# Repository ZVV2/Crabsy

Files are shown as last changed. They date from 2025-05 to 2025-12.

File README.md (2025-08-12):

<p align="center">
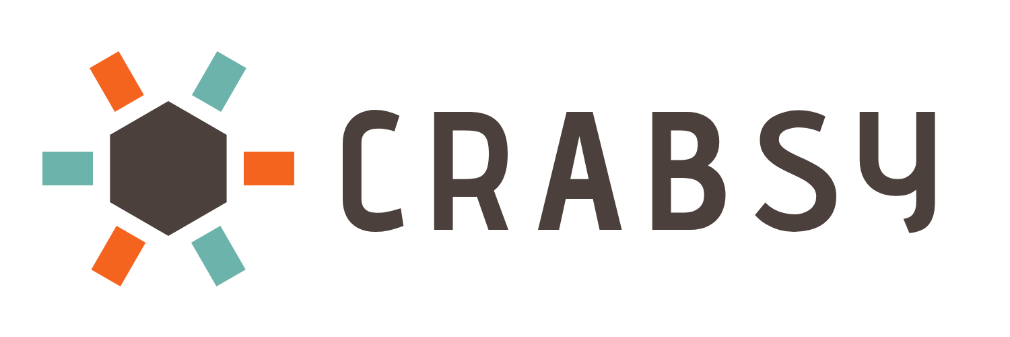
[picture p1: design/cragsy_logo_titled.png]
    
</p>

---

A robotic crab, designed as a hexapod to be taught and controlled by AI.

This repo contains purely the hardware (construction, electronics and related calculations). The operating system [CrabOS](https://github.com/ZVV2/CrabOS), the APIs [CrabAPIs](https://github.com/ZVV2/CrabAPI) and the AI/simulation [CrabRave](https://github.com/ZVV2/CrabRave) each have their own repos.

<p align="center">
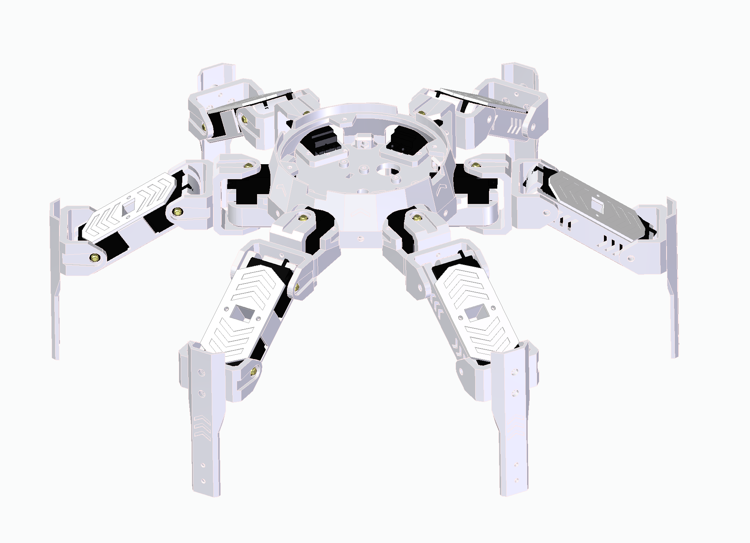
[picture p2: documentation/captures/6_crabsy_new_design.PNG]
    
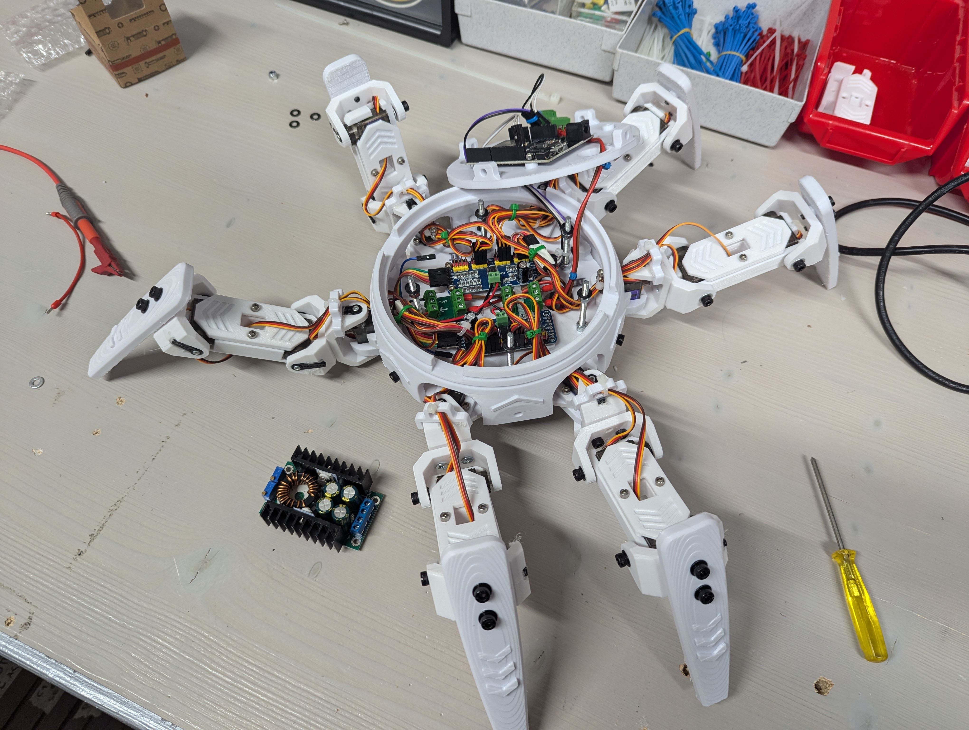
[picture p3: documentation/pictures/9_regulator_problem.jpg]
    
</p>

A full documentation is available [here](documentation/README.md). For further reading on the projects history and creation, read the [project log](documentation/project_log.md). To get an overview over recent changes see the [changelog](CHANGELOG.md).

The robot is designed and created by a [small team](https://github.com/ZVV2) as a fun little side project. We have no economic goals with it, feel free to use whatever you deem useful and let us know!

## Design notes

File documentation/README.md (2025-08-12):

<p align="center">
    
</p>

--- 

Full documentation for the Crabsy robot for the version 0.1.0/2025/05/27. For details on design/build choices and project history see the [project log](./project_log.md).

<h2>Overview</h2>

- [Construction](#construction)
- [Electronics](#electronics)

## Construction

## Electronics

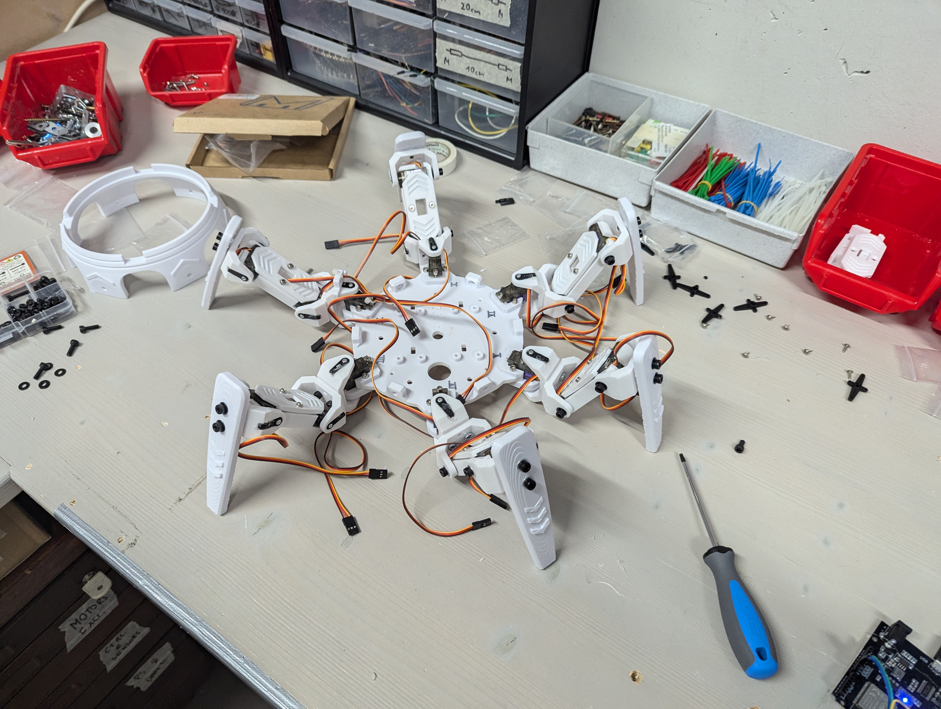
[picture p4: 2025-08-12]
documentation/pictures/2_hexapod_done_1.jpg

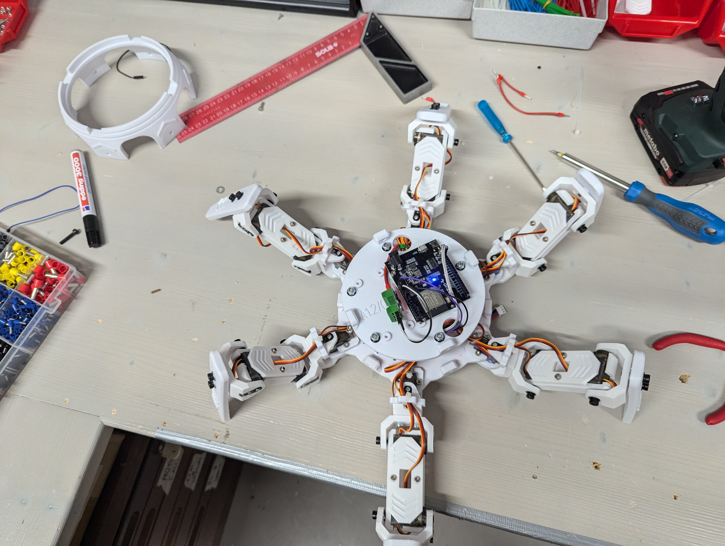
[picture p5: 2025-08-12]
documentation/pictures/7_next_layer_3.jpg

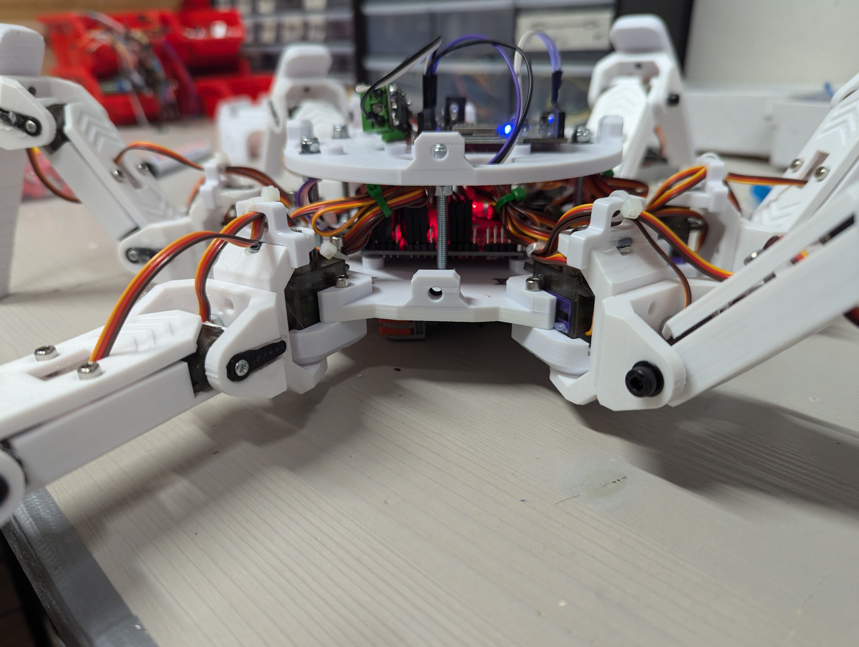
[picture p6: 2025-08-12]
documentation/pictures/6_next_layer_2.jpg

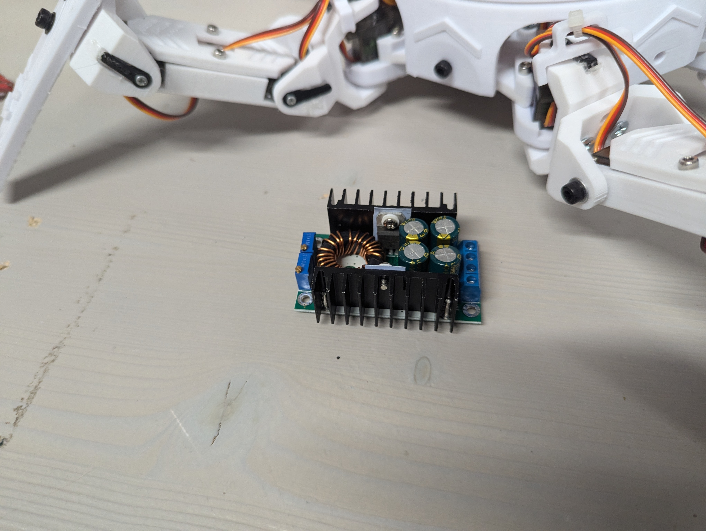
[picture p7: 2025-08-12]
documentation/pictures/10_regulator.jpg

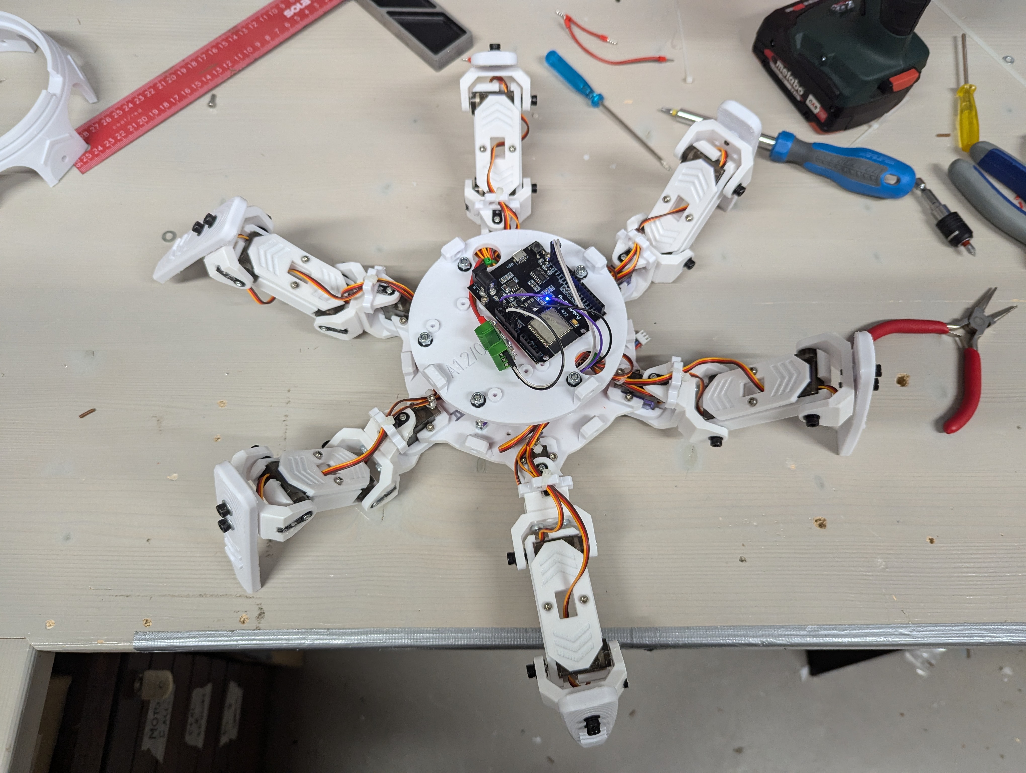
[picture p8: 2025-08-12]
documentation/pictures/8_next_layer_4.jpg

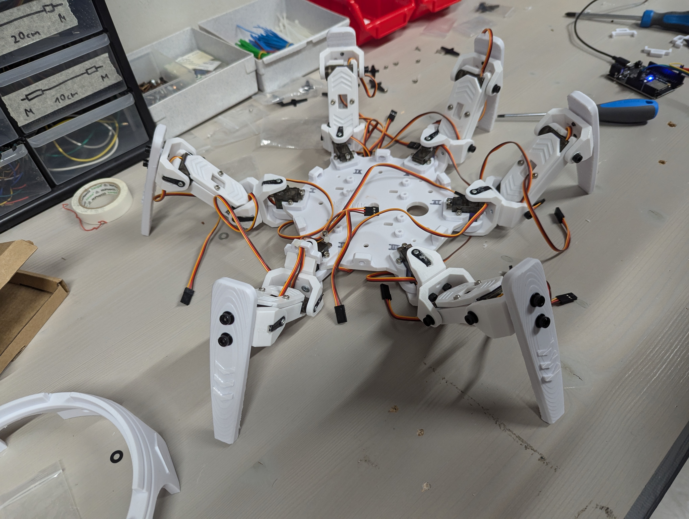
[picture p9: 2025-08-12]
documentation/pictures/4_hexapod_done_3.jpg

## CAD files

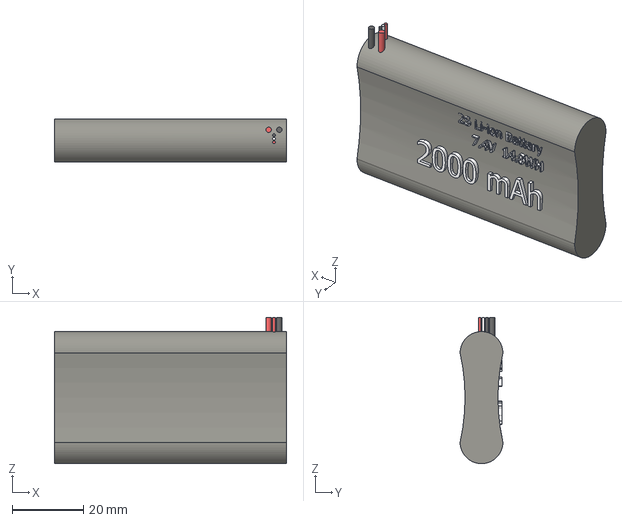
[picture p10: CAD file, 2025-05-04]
construction/a1_base/e_electronics/e2_battery_7.4V_2000mah/raw/Battery_Li-ion.stp
65.0 x 12.0 x 41.0 mm

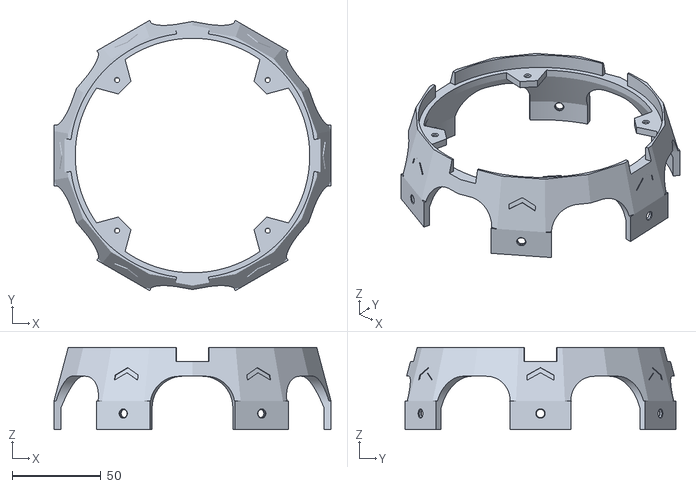
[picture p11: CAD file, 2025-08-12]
construction/a1_base/stl/3_lower_carapace.stl
156.0 x 152.4 x 46.2

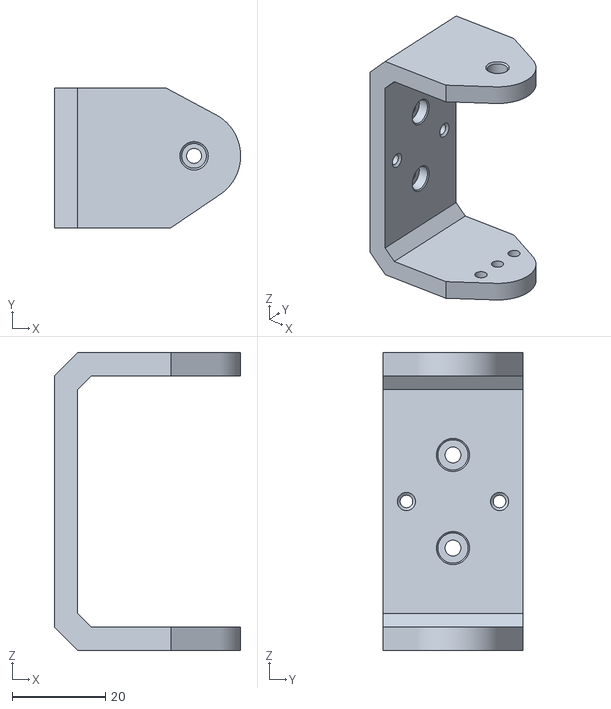
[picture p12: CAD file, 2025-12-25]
construction/a2_leg/stl/5_connector.stl
40.0 x 30.0 x 64.0

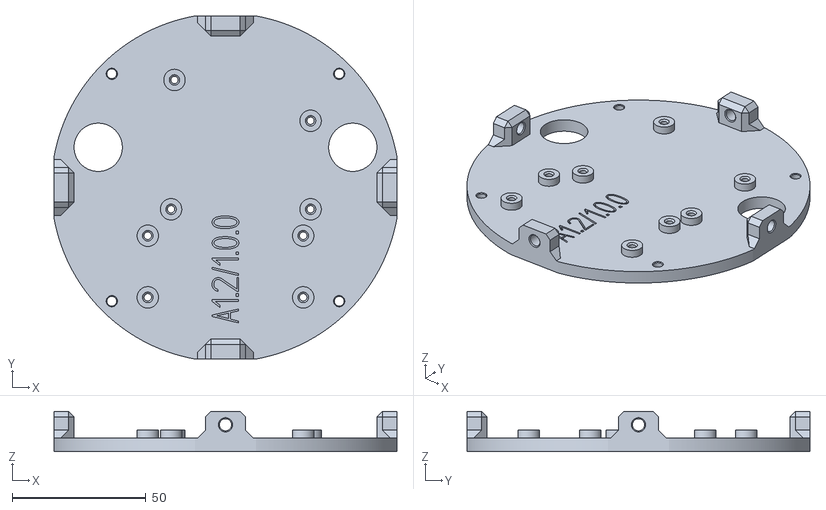
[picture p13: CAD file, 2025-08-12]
construction/a1_base/stl/2_top_plate.stl
128.0 x 128.0 x 15.0

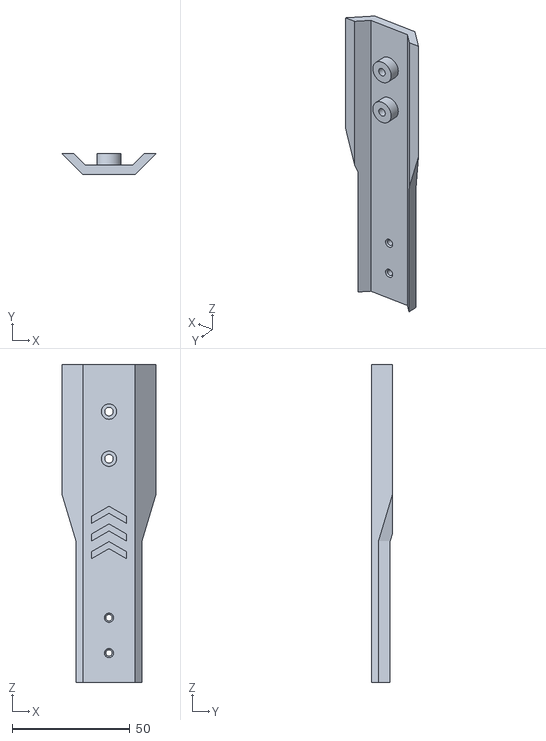
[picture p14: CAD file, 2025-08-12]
construction/a2_leg/stl/4_foot_shell.stl
40.0 x 9.00 x 135.0

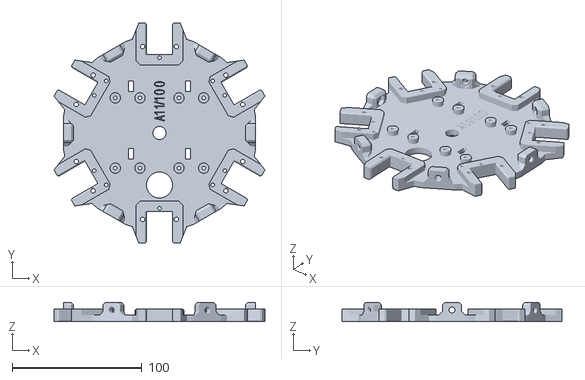
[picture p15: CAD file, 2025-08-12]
construction/a1_base/stl/1_base_plate.stl
162.4 x 169.0 x 15.0

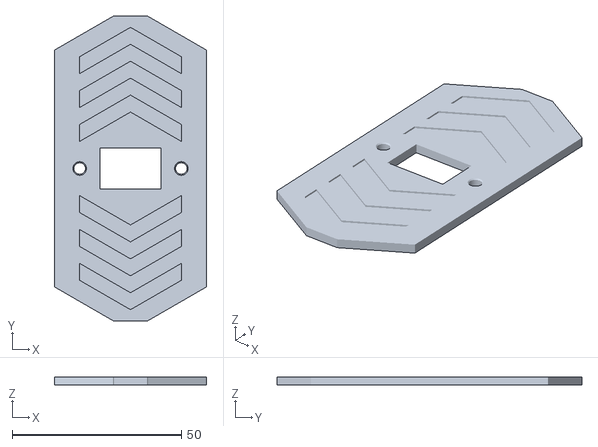
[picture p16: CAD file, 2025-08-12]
construction/a2_leg/stl/3_middle_cap.stl
45.0 x 90.0 x 2.50

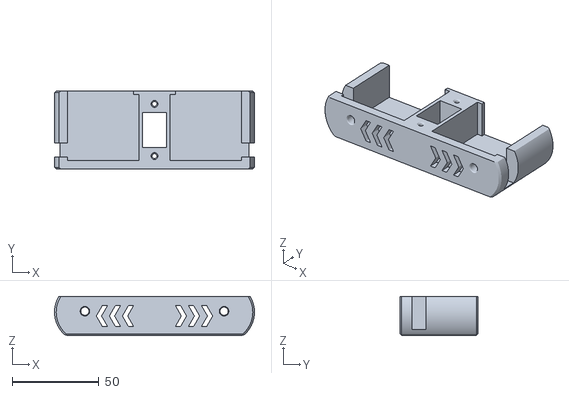
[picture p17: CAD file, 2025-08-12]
construction/a2_leg/stl/2_middle_segment.stl
115.0 x 45.0 x 22.5

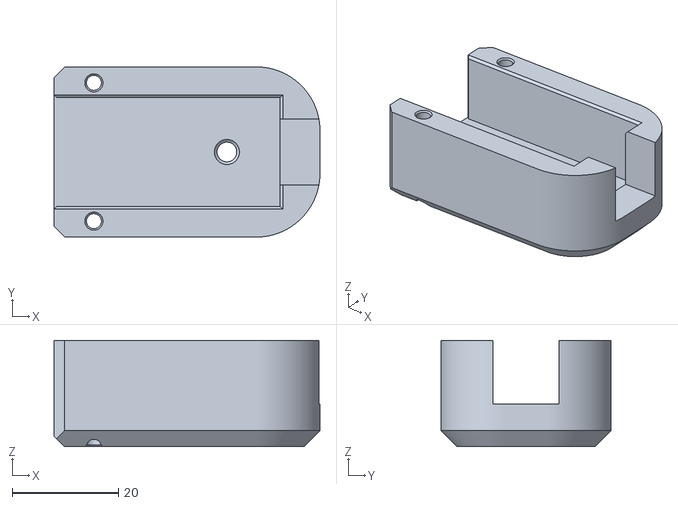
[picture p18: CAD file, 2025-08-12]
construction/a2_leg/stl/1_lower_bearing.stl
50.0 x 32.0 x 20.0

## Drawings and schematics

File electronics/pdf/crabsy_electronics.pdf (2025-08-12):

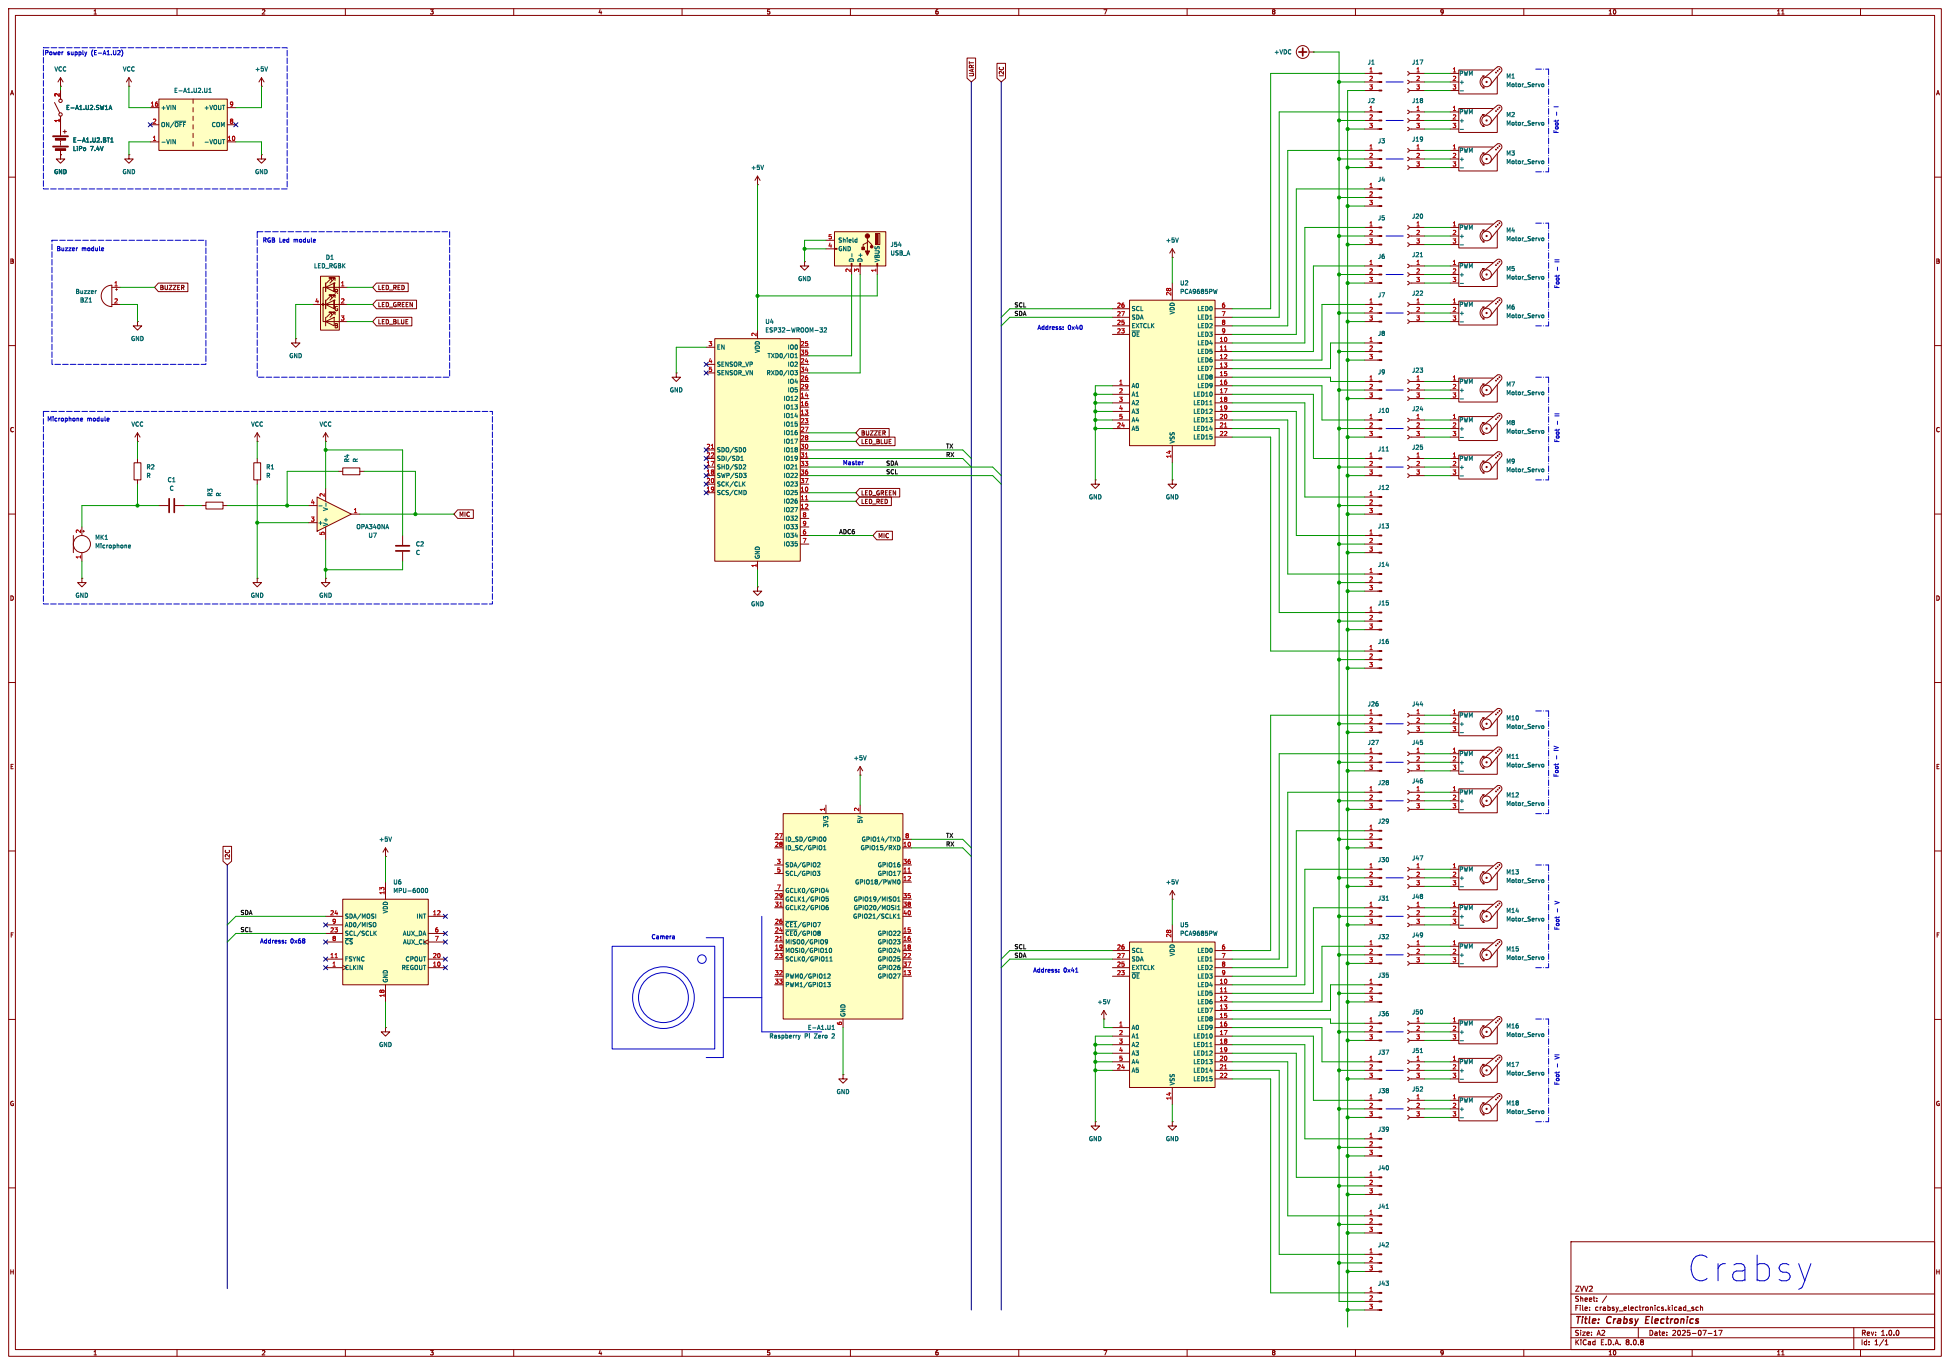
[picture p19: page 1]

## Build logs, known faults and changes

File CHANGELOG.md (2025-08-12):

# 0.1.0/2025/05/27

- Created a first version, including a first test build and an outline for the project structure and documentation

# 0.2.0/2025/08/12

- Complete rework of structure for motor upgrades
- Design changes with more edges and angles instead of rounds

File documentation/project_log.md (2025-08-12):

<h1>Project Log</h1>

- [Restarting project (2025/05/12)](#restarting-project-20250512)
- [Road towards first build (2025/05/26)](#road-towards-first-build-20250526)
  - [Body and baseplate upgrades](#body-and-baseplate-upgrades)
  - [New design of leg segments](#new-design-of-leg-segments)
- [Creating first build (2025/05/27)](#creating-first-build-20250527)
  - [Issues and solution ideas for next design](#issues-and-solution-ideas-for-next-design)
- [Second build (2025/06/18)](#second-build-20250618)
  - [First tests with second build (12/08/2025)](#first-tests-with-second-build-12082025)

## Restarting project (2025/05/12)

The "Crabsy" project has been elevated from a small experiment of @SamuelNoesslboeck to a Team project to improve the quality of software and especially AI. As a first step, the repo has been moved an split up, with this repo containing only the construction and electronics from now on (everything concerning the hardware).

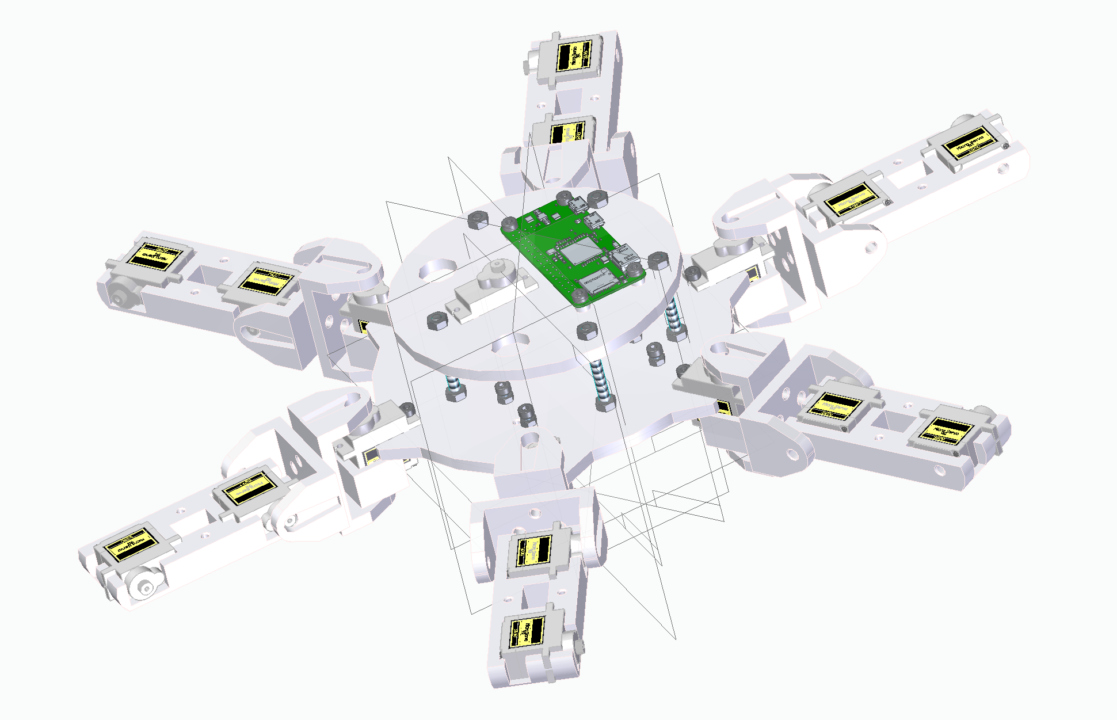
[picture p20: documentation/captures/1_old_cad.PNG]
Old construction state


## Road towards first build (2025/05/26)

### Body and baseplate upgrades

For the new AI controlled version, a first build is currently in the making, with focus on basic controls for first tests. For that a new body was constructed, using a more enhanced baseplate, that correctly embeds all components.

<p align="center">
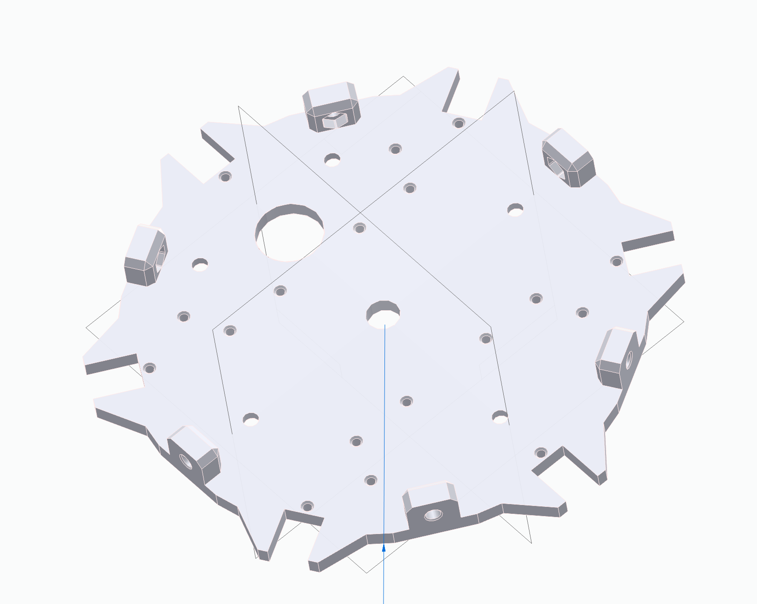
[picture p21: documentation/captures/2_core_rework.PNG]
    
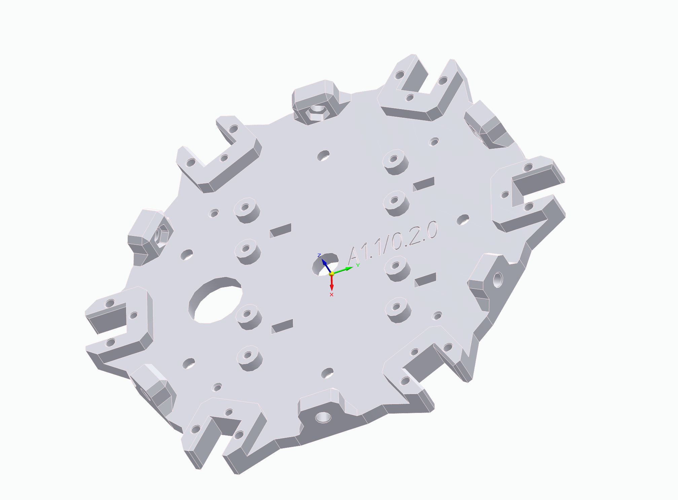
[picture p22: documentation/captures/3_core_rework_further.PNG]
    
</p>

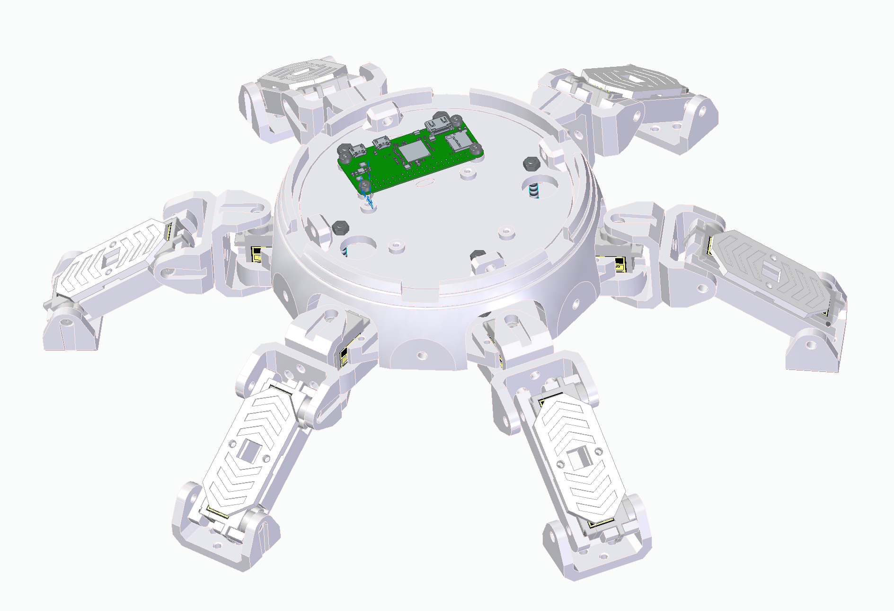
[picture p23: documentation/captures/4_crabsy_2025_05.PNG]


### New design of leg segments

As it is common with hexapods, the last segments of the legs are rotated 90° downwards, resulting in the robot standing when all angles are set to their neutral position. Similar to crabs, the segments have been designed to resemble shells.

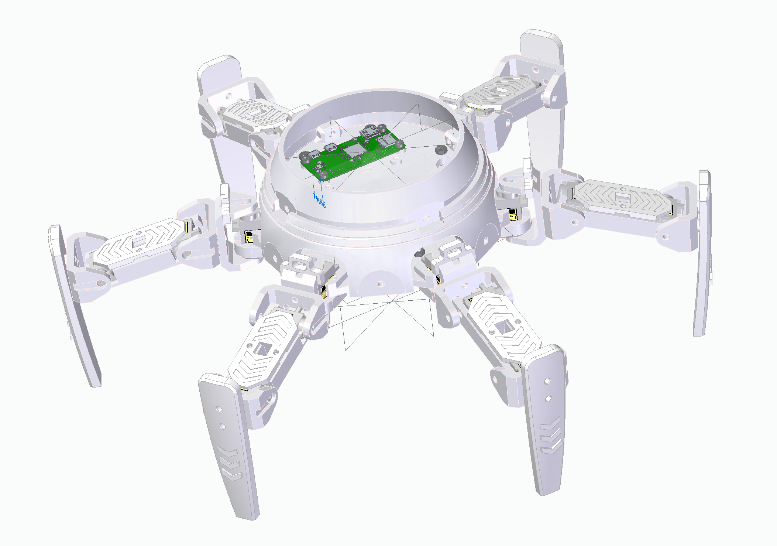
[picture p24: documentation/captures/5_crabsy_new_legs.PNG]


## Creating first build (2025/05/27)

First all leg segments and the baseplate have been printed out and assembled accordingly. 

<p align="center">
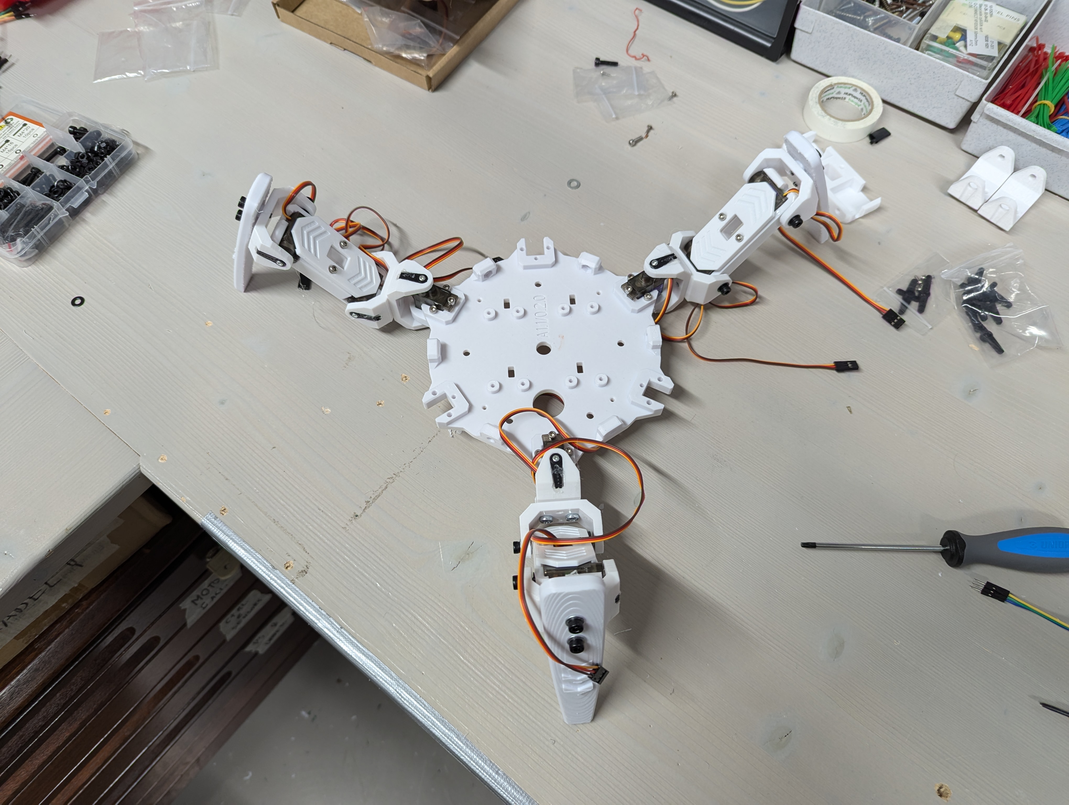
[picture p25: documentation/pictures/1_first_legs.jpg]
    
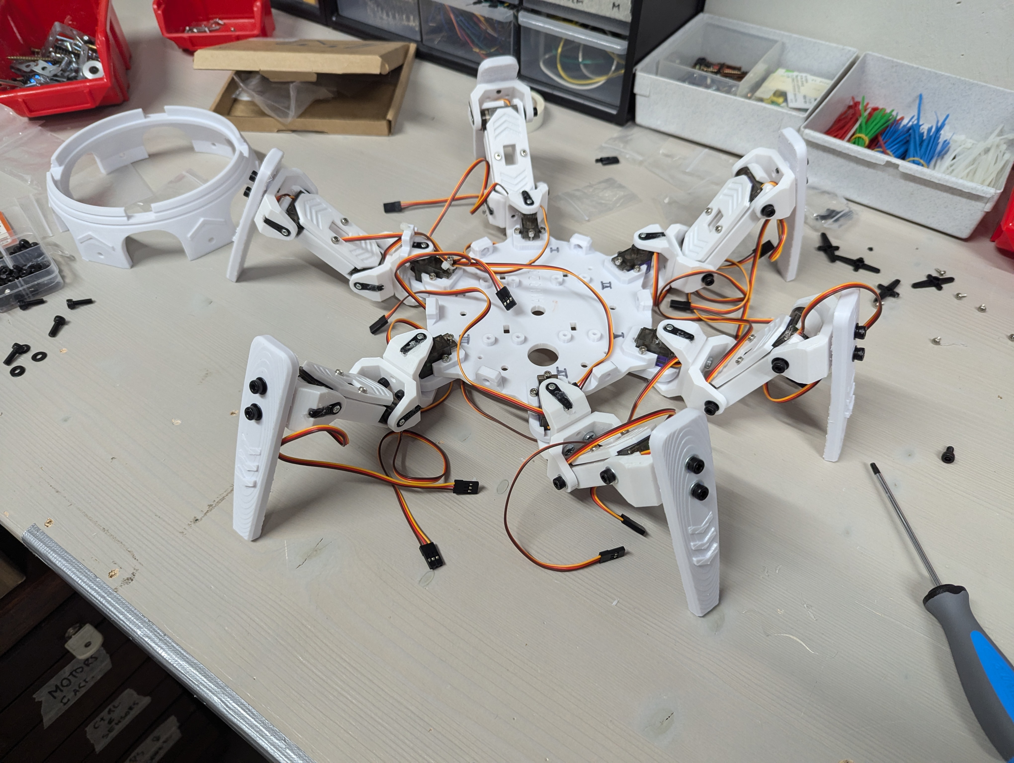
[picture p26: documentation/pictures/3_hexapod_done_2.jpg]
    
</p>

Afterwards, the baseplate has been equipped with it's electronic components, which are:

- The two PCA9685 16 channel servo controllers on top of the baseplate
- The battery module strapped to the bottom

Additionally, the next layer of the base has been attached to the passing screws, using 

- An ESP32 (NodeMCU32S) and
- A buck converter to 5V

as it's electronics. The finished build looked as follows:

<p align="center">
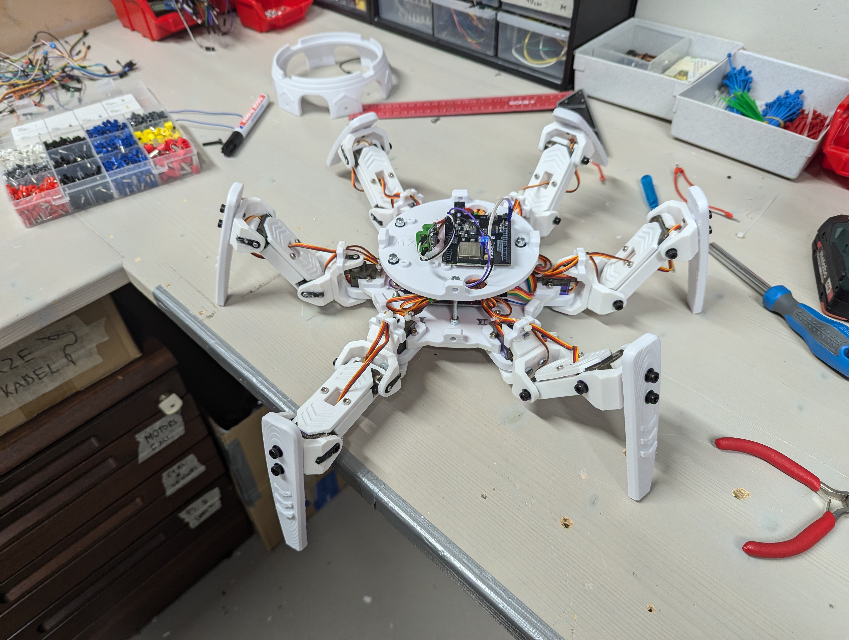
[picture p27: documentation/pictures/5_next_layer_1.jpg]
    
    
</p>

The design of the lower hull part worked pretty well too by being attached to the bottom base layer with screws driving into nuts that have been slotted into fitting cut-outs as it is usual for 3D-printed parts.

### Issues and solution ideas for next design 

- The first major issue was the insufficient supply with power provided by the buck converters. Even with high-power buck converters the motors were unable to archive their promised load torque
- Even if less motors are used so they do reach the promised torque, they still prove to be much too weak for the desired strength of the robot
- The solution is to take medium servos instead of micro servos, as they are able to take 7.4V directly, so they do not require a buck converter in advance!

## Second build (2025/06/18)

In the second build, larger servo motors are used (medium sized ones). This requires quite a rework of the legs and their assembly to the baseplate. 

### First tests with second build (12/08/2025)

The second build proves to be a large success in most areas. The motors are supplied with more than enough power and can lift the weight of the robot with ease, some minor issues include:

- The servo horns should not be glued into the sockets anymore, a more permanent solution has to be found
  - There are metallic servo flanges available for purchase online, I ordered some of them and will adjust the build to the new horns soon

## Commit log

2025-05-04 init commit with old files
    [Battery_Li-ion.stp, a1_base.cfg, a2_foot.cfg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]
2025-05-13 starting to rework old design
    [a_crabsy.cfg]
2025-05-13 massive advances to construction
    [1_lower_bearing.stl, a2_foot.cfg, a_crabsy.cfg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]
2025-05-14 renaming stuff and making huge CAD progress
    [1_lower_bearing.stl, Battery_Li-ion.stp, a1_base.cfg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]
2025-05-14 adding small details from save
    [a_crabsy.cfg]
2025-05-15 reworking leg parts
    [1_lower_bearing.stl, a2_leg.cfg, a_crabsy.cfg]
2025-05-22 electronics upgrade
    [Battery_Li-ion.stp, a1_base.cfg, crabsy_electronics.kicad_pcb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]
2025-05-25 adding cable lead
    [6_cable_lead.stl, a2_leg.cfg]
2025-05-26 improving assembly and writing project log
    [MicroServo-SG90.step, a2_leg.cfg, a_crabsy.cfg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]
2025-05-26 exporting carapace for printing
2025-06-19 final changes for first build
    [2_top_plate.stl, a2_leg.cfg, a_crabsy.cfg]
2025-06-20 start of new leg construction
    [a2_leg.cfg, e1_mg996r.cfg, e1_micro-servo-sg90.cfg]
2025-06-22 kicking off second build
    [a2_leg.cfg]
2025-06-23 adjusting baseplate to new legs
    [a1_base.cfg, a2_leg.cfg, a_crabsy.cfg]
2025-06-25 first assemblies
    [a1_base.cfg, a2_leg.cfg, a_crabsy.cfg]
2025-07-01 middle plate adjustments
    [a2_leg.cfg]
2025-07-03 finishing foot and making first test print
    [1_lower_bearing.stl, 2_middle_segment.stl, 3_middle_cap.stl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]
2025-07-06 new carapace design
    [1_base_plate.stl, 2_top_plate.stl, a1_base.cfg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]
2025-07-12 printing progress
    [3_lower_carapace.stl]
2025-07-13 finishing first version of second build
    [4_foot_shell.stl, a1_base.cfg, a2_leg.cfg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]
2025-07-17 updating schematics
    [a1_base.cfg, a_crabsy.cfg, crabsy_electronics.kicad_sch]
2025-07-17 exporting and README updating
    [2_top_plate.stl]
2025-07-22 adjusting foot shell
    [4_foot_shell.stl, a_crabsy.cfg]
2025-08-17 new flanges for servos
    [5_connector.stl, a2_leg.cfg]
2025-12-25 increased stability of connectors
    [5_connector.stl]
